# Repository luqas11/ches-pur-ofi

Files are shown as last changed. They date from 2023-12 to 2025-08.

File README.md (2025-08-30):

# ches-pur-ofi

### What is this
This project is the **firmware** and **PCB design** for the hardware interface between the [Sega Model 2](https://emulation.gametechwiki.com/index.php/Sega_Model_2) emulator and **a custom homemade cockpit** which has two **pedals**, a **steering wheel**, an **H shifter** and an **analog speedometer**. The idea is to play [Daytona USA](https://en.wikipedia.org/wiki/Daytona_USA) on the emulator while using the cockpit controls and to keep the speedometer pointer in sync with the game car speed. An [Arduino Leonardo](https://docs.arduino.cc/hardware/leonardo) board makes this interface possible, reading the input values and sending them to the PC as PC Joysick buttons and axes. Also, the board controls the servo that drives the speedometer pointer and processes the car speed value given by the emulator. A custom PCB design simplifies the setup process, allowing the user to just plug the *Leonardo* into the PCB and play, without additional wiring.  

The repo has the following project components:
- A **LUA script** that runs in the emulator and broadcasts the car speed value to the *Leonardo*
- A **C++ sketch** that is the firmware running inside the *Leonardo*, which processes the controls inputs and the speedometer motor output
- A **custom PCB** that has some pins to simplify the electrical connections between the *Leonardo* and the cockpit potentiometers and buttons

### How to use it
While in the cockpit, plug the *Leonardo* to the board and the USB to the PC. Run the emulator from the `Daytona USA.bat` script, and specify the *Leonardo* COM port number when asked to. After that, the game shuld start with all the controls operational. Axes calibration process is explained in the `firmware` readme file, and is usually needed after a hardware change (i.e. after replacing potentiometers). In the top left corner an informative text shows the port connection status, and it's behavior is also explained in the `firmware` readme.

### Some screenshots
#### Gameplay with a successful connection to the *Leonardo* (notice the top-left corner text displaying the COM port name in green):
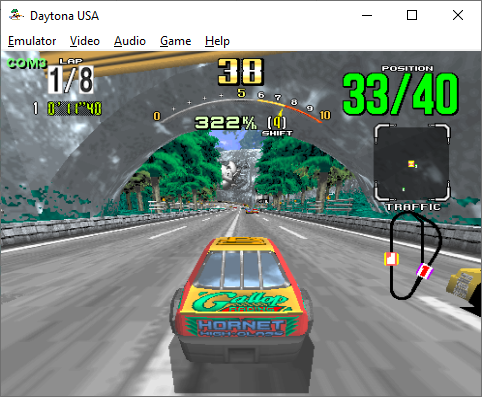
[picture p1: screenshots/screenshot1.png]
Gameplay with successful connection
  

#### Gameplay with the connection to the *Leonardo* lost (notice the top-left corner text displaying the COM port name in red):
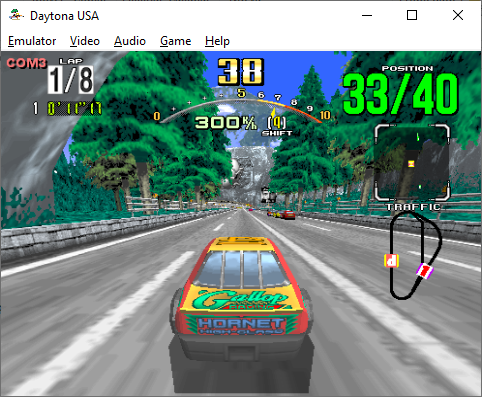
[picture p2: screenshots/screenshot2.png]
Gameplay with lost connection
  

#### PCB layout:
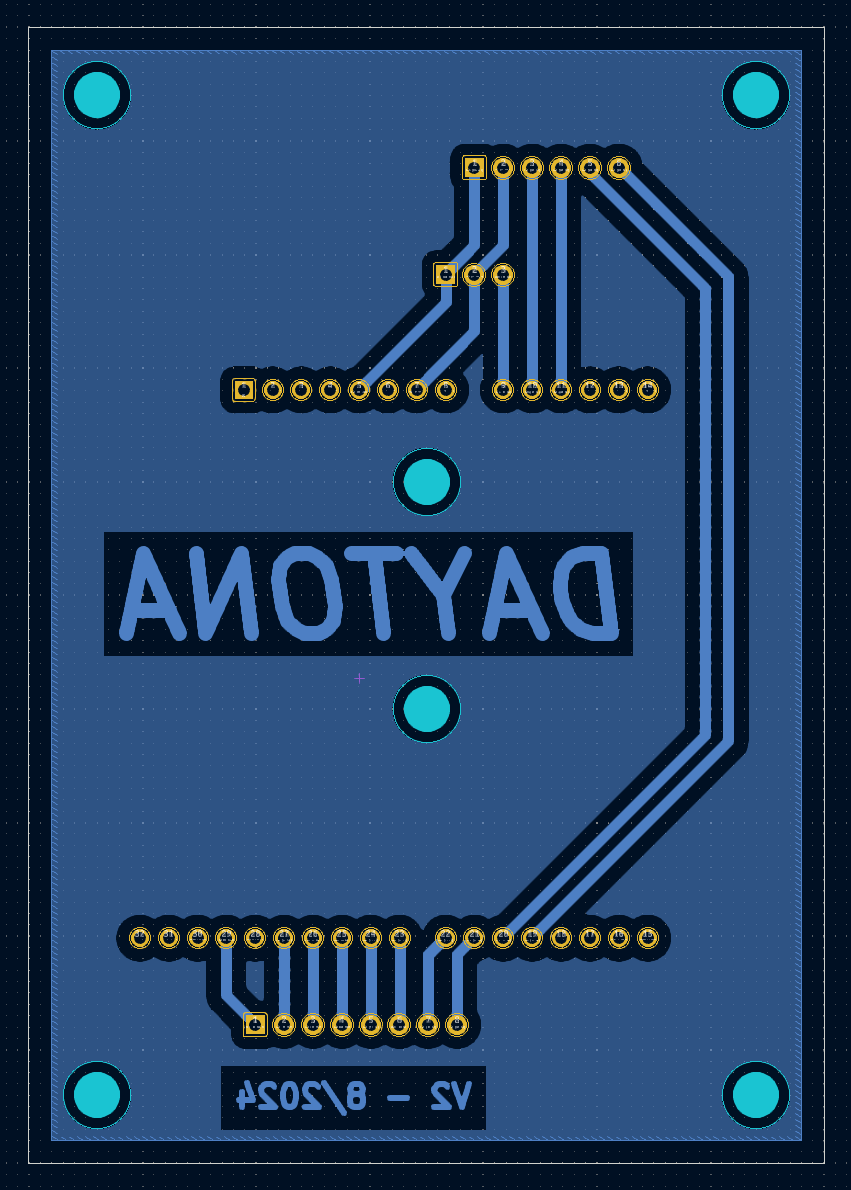
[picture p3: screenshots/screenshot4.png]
  

#### PCB 3D model:
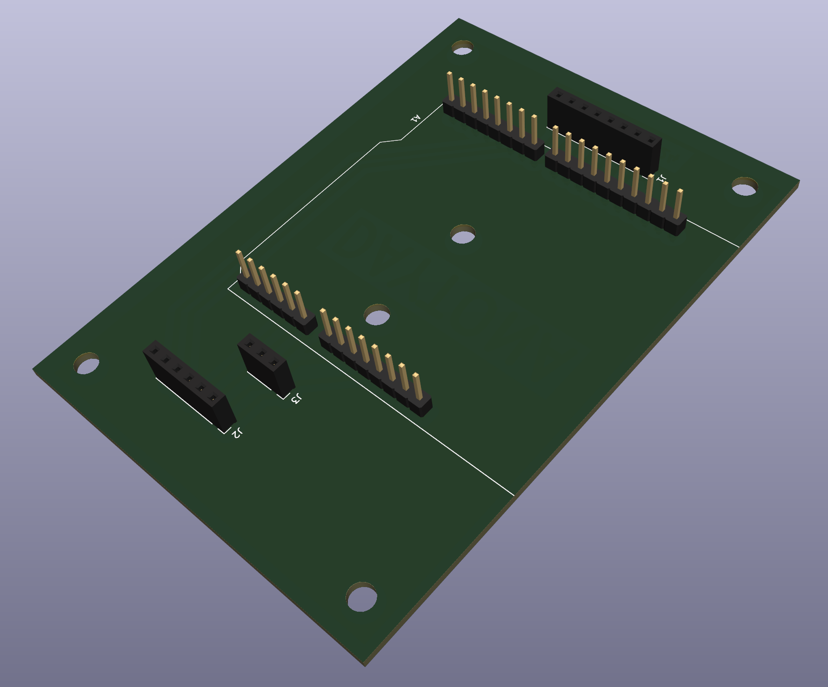
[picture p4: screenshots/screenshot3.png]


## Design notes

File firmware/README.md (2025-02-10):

# Firmware

### How this works
This firmware handles up to 8 buttons, 3 axes, and a servo motor. In the emulator, the buttons are mapped to the car shifts and the coin input, the axes are mapped to the steering, brake and accelerator, and the servo moves the physical speedometer pointer. The [Arduino Joystick Library](https://github.com/MHeironimus/ArduinoJoystickLibrary) makes this possible by configuring the *Leonardo* to appear as a PC Joystick to the PC, and giving an API that allows the Joystick buttons and axes to be pressed and moved from the board.  

### How to debug analog inputs
By setting the `DEBUG_MODE` constant to `true`, the firmware stops using the `Joystick` object and starts sending the analog inputs raw values to the serial monitor. It's useful to calibrate or debug analog inputs that are not working as expected, or to recalibrate an input after a potentiometer replacement.

### How to calibrate analog inputs
The analog inputs are constrained to the effective range of the raw values of the physical potentiometers, and mapped to a range between `0` and `1023`. Neither the wheel nor the pedals make perfect use of the whole potentiometer rotation range, so the constraining and the mapping are always necessary to normalize the raw values.  

For the pedals, the effective range must be specified in the firmware to make it work properly. For example:
```
// A brake pedal works between the raw values of 730 and 960.
// The firmware constrains it to a smaller range to add a tolerance margin, for example between 750 and 940.
// After that, it maps that range to a 0-1023 range to make the Joystick library perform a full range axis movement.
int brake = analogRead(A2);
brake = constrain(brake, 750, 940);
brake = map(brake, 750, 940, 0, 1023);
```  
Similarily, the steering wheel raw reading is not acceptable for the axis emulation. Assuming that the wheel uses the whole potentiometer range, the only relevant value for calibration is the centering. The center is sometimes mechanically deviated, so by specifying the center raw value the firmware calculates the widest range it can work, centering and mapping it. For example:
```
// A steering wheel is centered at the 525 raw value.
// The firmware calculates the closest border to the center, and takes that distance as the maximum available range for both directions (this makes the final range centered).
// After that, it constrains and maps the reading range to the new calculated range.
int steering = analogRead(A0);
int center = 525;
int range = min(1023 - center, center);
steering = constrain(steering, center - range, center + range);
steering = map(steering, center - range, center + range, 0, 1023);
```

### How to calibrate the speedometer
For the speedometer, since the rotation range of the servo is 180°, the received speed value must be mapped to a value between 180 and 0. The physical assembly of the speedometer could left the zero rotation point slightly displaced from the zero mark in the graphic scale, so an offset must be considered to correct it. At the maximum rotation point, the pointer will be at an arbitrary speed value, and that will be the maximum speed value to be used in the speed range mapping. For example:
```
// When the servo is set to zero rotation, the pointer is displaced by 6 degrees from the zero speed mark in the scale.
// An offset of 6 degrees is added to the minimum rotation value, so it will rotate between 180 - offset and 0 (180 means minimum rotation because the servo rotation direction is the opossite of the scale increasing direction).
// With the offset applied, rotating the servo to its maximum rotation point leaves the pointer at the 334 speed mark of the scale.
// The maximum speed value for the speed mapping is set to 334, to match the 0-334 effective range of the pointer over the scale.
int offset = 6;
int maxSpeed = 334;
int angle = map(min(speed.toInt(), maxSpeed), 0, maxSpeed, 180 - offset, 0);
```

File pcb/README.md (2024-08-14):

# PCB

This is a PCB design that simplifies physical wiring between the cockpit controls and the *Leonardo*. The circuit schematic and the PCB layout are printed in the `pcb-schematic.pdf` and `pcb-layout.pdf` files respectively. The 3D support model is a printable part that allows a solid attachment of the PCB to the cockpit structure.

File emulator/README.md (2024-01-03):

# Emulator

> [!IMPORTANT]  
> Since the **SEGA Model 2 Emulator** has no license file and it's webpage is down, i can't link a reference to the original author to give credits. The README file states that the author is *ElSemi*, and it's page (currently down) is http://nebula.emulatronia.com.

### How this works
The *Model 2* emulator calls the functions defined in the `daytona.lua` script during the game execution. That allows the development of additional features integrated with the emulation state and lifecycle.  
In this case, the `daytona.lua` script reads the current car speed from the RAM address `0x00505198`, and sends it through the COM port as a string with the format `XXXa`, where *XXX* is the speed value and *a* is the line ending character. It gets the board's COM port number from a configuration file named `com_port.txt`, which has a single line string with the port name in the format `COMX`, with *X* as the port number.

### Configuration
As mentioned, the COM port number is picked from the `com_port.txt` configuration file where it is written in a specific string format. The `Daytona USA.bat` script allows the user to interactivelly generate this file if it's not present. At launch, it asks the user for the port number and generates the file with the port name string. If the file already exists, it launches the game without asking anyting.

### Port status messages
In the top left corner of the screen, a small green or red text indicates the port connection status:
- If the script can't find the configuration file, the `NULL` text is shown in **red**
- If the script finds the file but can't establish a connection, the port name is shown in **red**
- If the script finds the file and establishes a successful connection, the port name is shown in **green**
- If the script loses connection with the port at any time of the gameplay, the port name turns into **red**

Notice that the script will not retry the port connection if it's lost during the gameplay, so a emulator reset is needed for reconnection.

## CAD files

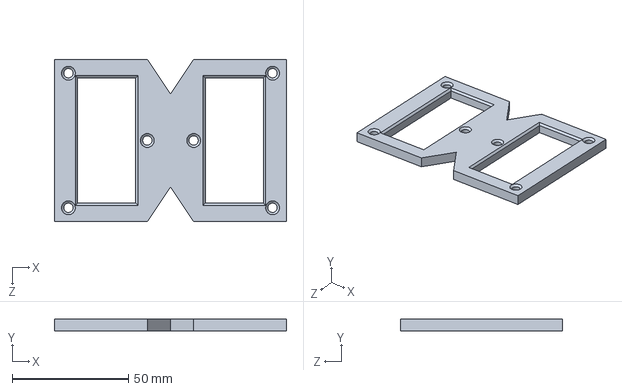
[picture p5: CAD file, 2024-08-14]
pcb/support.SLDPRT
100.0 x 5.00 x 70.0 mm

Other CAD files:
pcb/support.STL

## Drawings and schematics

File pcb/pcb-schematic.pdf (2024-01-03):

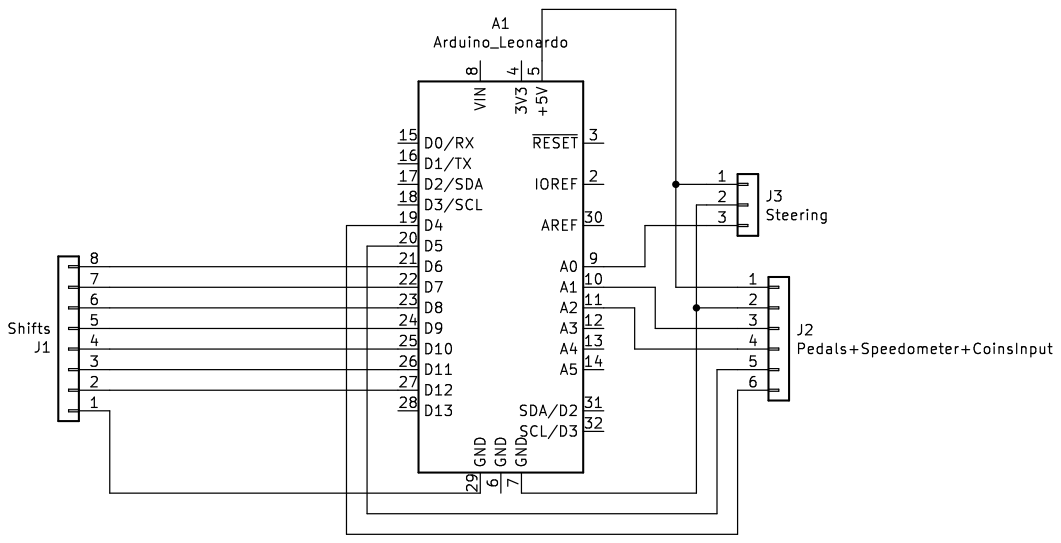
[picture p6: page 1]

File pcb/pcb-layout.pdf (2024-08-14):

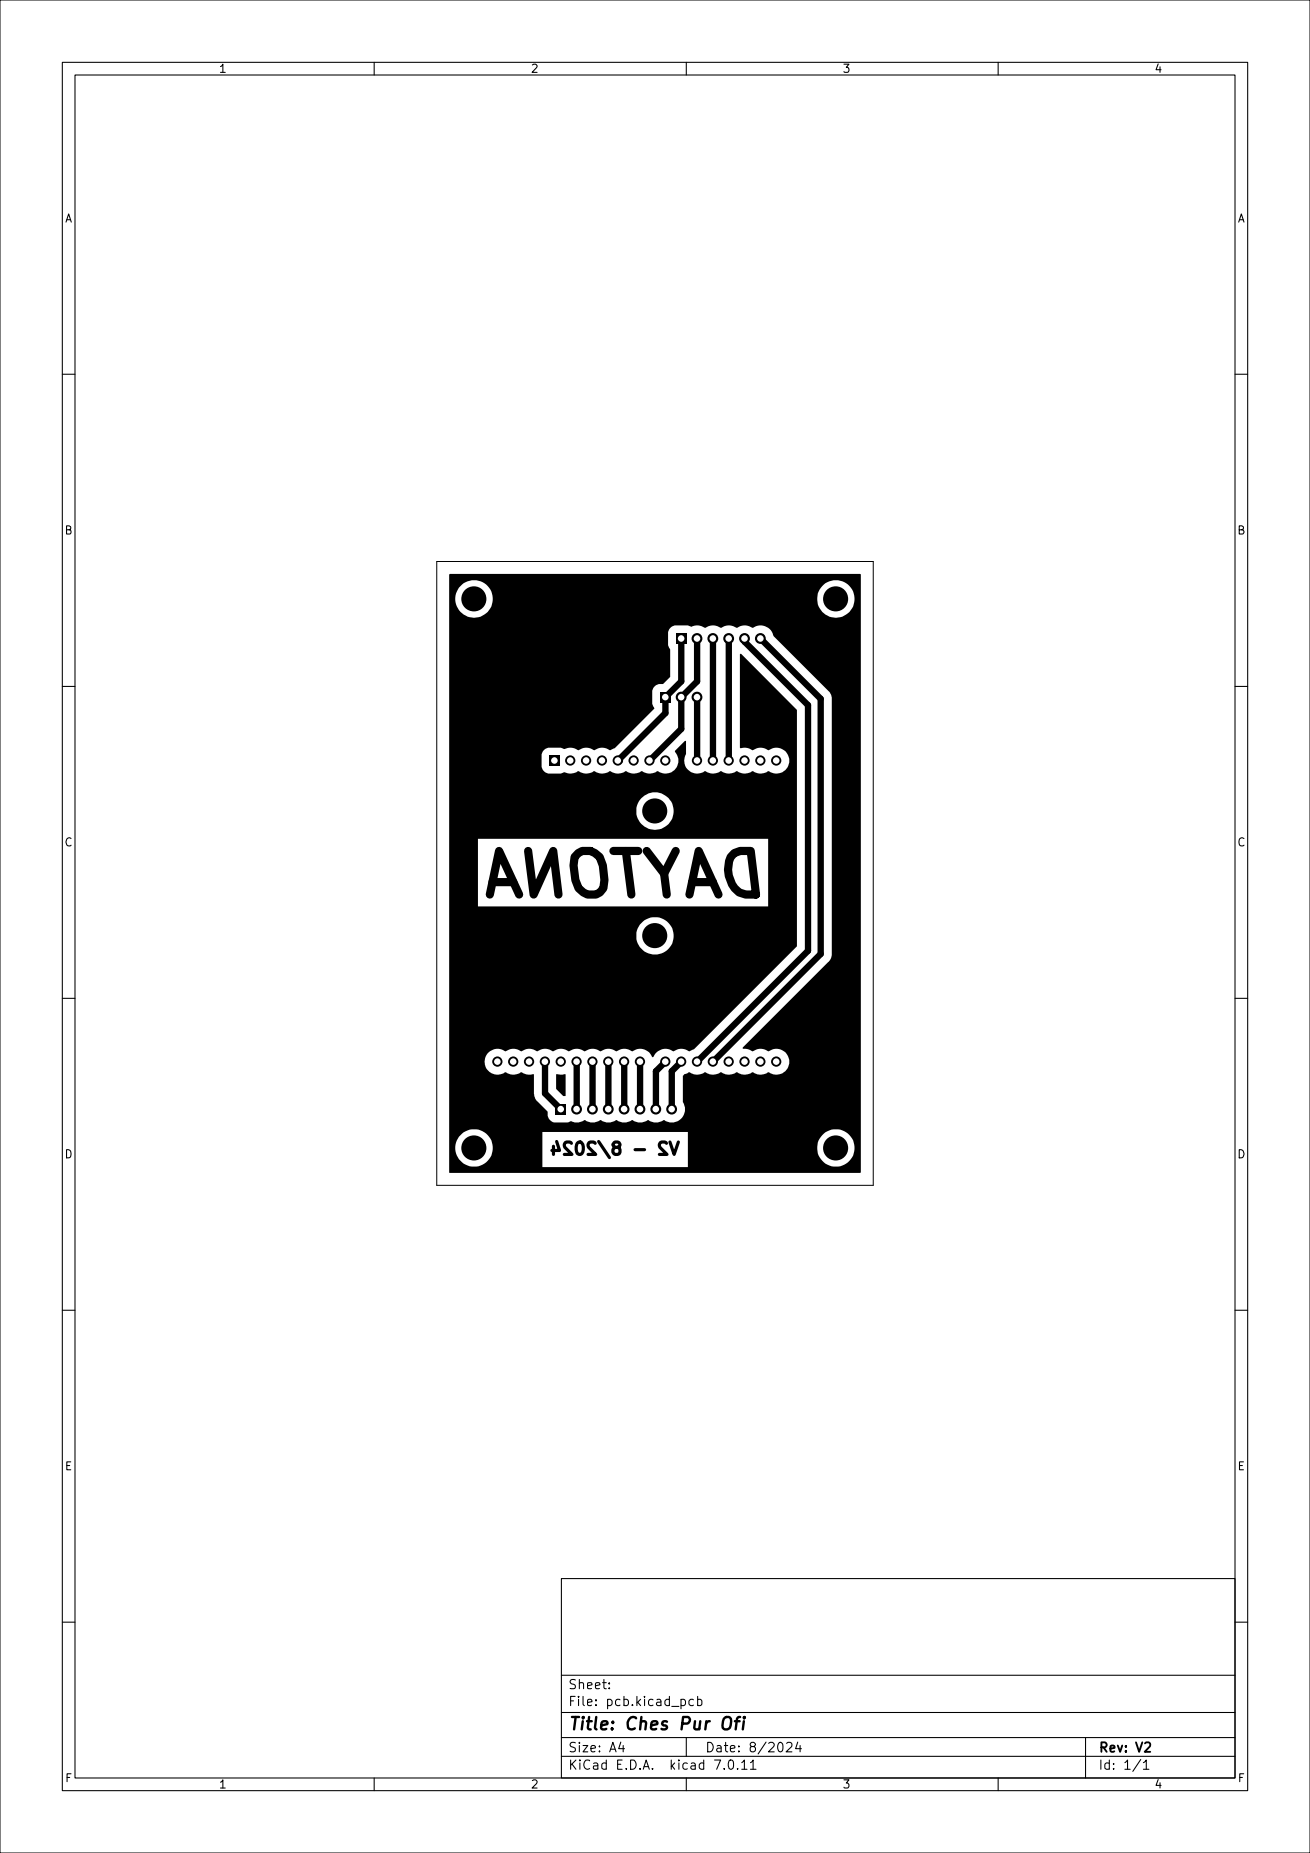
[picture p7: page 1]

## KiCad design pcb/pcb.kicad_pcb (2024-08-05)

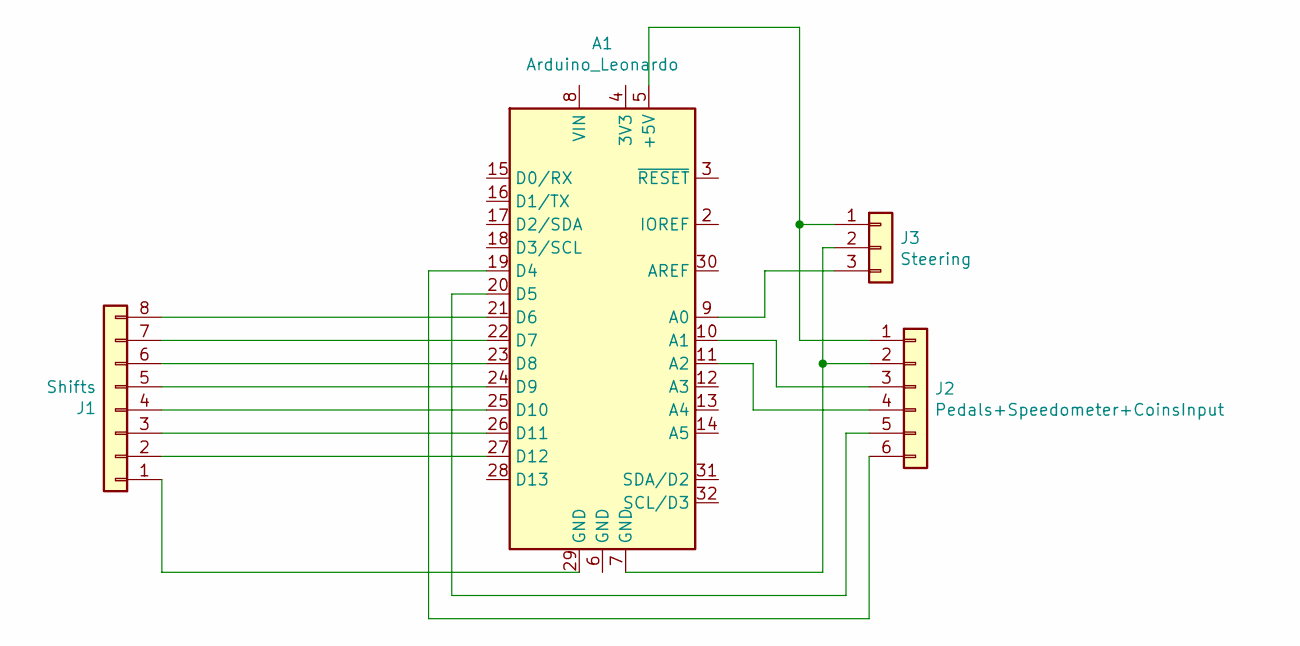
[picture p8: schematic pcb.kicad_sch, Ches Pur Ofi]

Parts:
A1: Arduino_Leonardo
J1: Shifts; PinSocket_1x08_P2.54mm_Vertical
J2: Pedals+Speedometer+CoinsInput; PinSocket_1x06_P2.54mm_Vertical
J3: Steering; PinSocket_1x03_P2.54mm_Vertical

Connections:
unnamed: A1.5 (+5V), J2.1, J3.1
unnamed: A1.9 (A0), J3.3
unnamed: A1.10 (A1), J2.3
unnamed: A1.11 (A2), J2.4
unnamed: A1.19 (D4), J2.6
unnamed: A1.20 (D5), J2.5
unnamed: A1.21 (D6), J1.8
unnamed: A1.22 (D7), J1.7
unnamed: A1.23 (D8), J1.6
unnamed: A1.24 (D9), J1.5
unnamed: A1.25 (D10), J1.4
unnamed: A1.26 (D11), J1.3
unnamed: A1.27 (D12), J1.2
unnamed: A1.29 (GND), J1.1
unnamed: A1.7 (GND), J2.2, J3.2

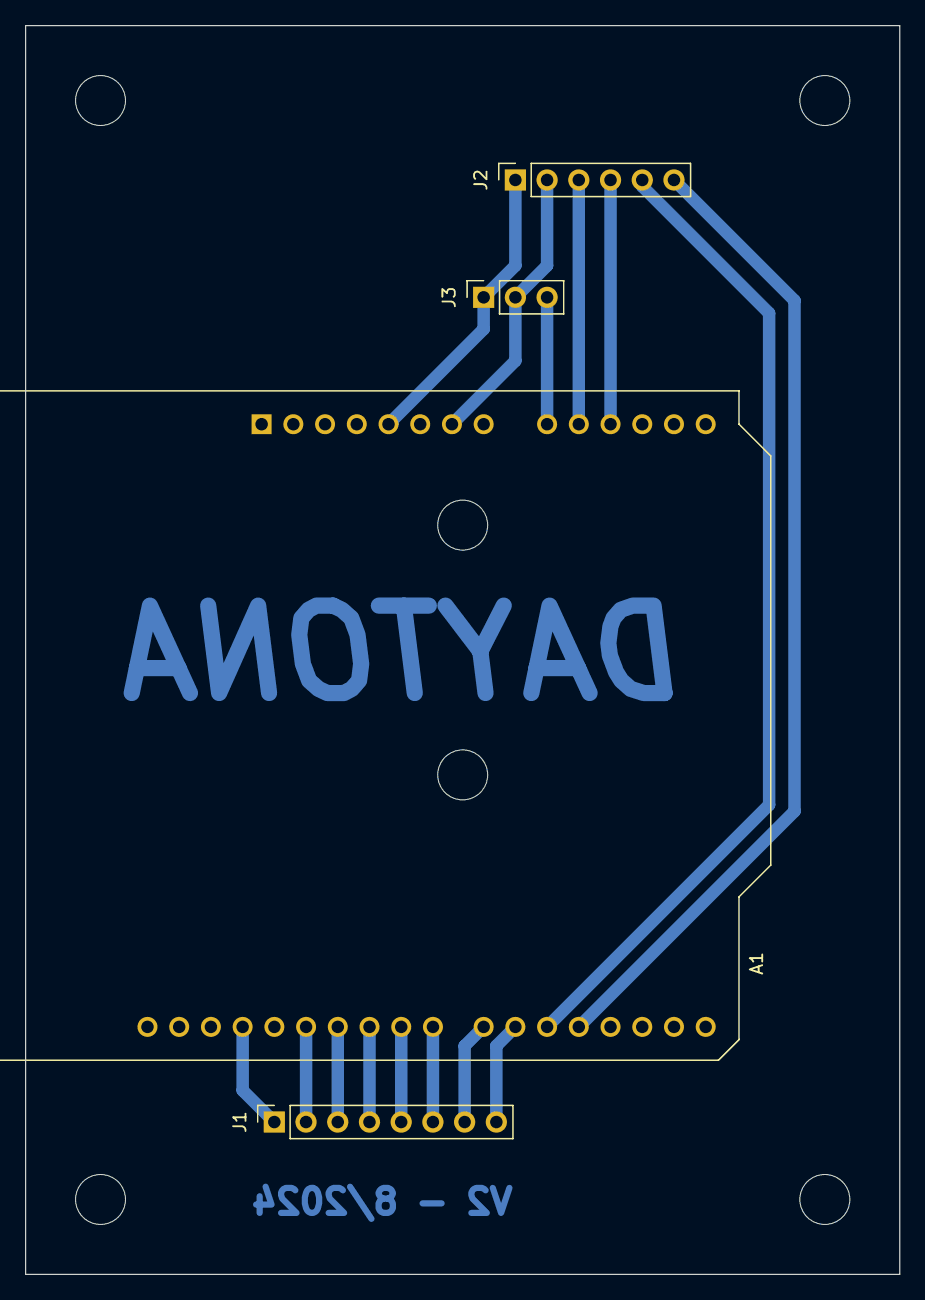
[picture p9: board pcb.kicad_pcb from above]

Board: 2 copper layers, 70.0 x 100.0 mm, 4 parts (0 on the bottom side), 15 nets.

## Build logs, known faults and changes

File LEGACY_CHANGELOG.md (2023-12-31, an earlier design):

# Historial de versiones

## Versión 1.3.0 (11/1/2023)
*Probado en la máquina del Daytona.*

#### Software:
- Calibración de potenciómetros
- Creación de script interactivo para autogenerar el archivo `com_port.txt` e iniciar el juego

## Versión 1.2 (8/12/2021)
*Probado en la máquina del Daytona.*
#### Software:
- Reemplazo de la comunicación via script C# por comunicación serie directa para el envío de la velocidad actual
- Handleo de errores de conexión con el puerto COM
- Ajustes de código en el sketch

## Versión 1.1 (4/4/2021)
*Probado con PCB propio.*
#### Software:
- Cuatro entradas digitales nuevas, ocho en totaL
- Modificación de script LUA para comunicar el valor de la velocidad actual
- Creación de un script C# para enviar la salida del LUA a Arduino por comunicación serie
- Salida para el servo del velocímetro, basado en el valor recibido del script C#

#### Hardware:
- PCB con pines para Arduino y los conectores de E/S

## Versión 1.0 (19/4/2019)  
*Probado con protoboard.*
#### Software:
- Tres entradas analógicas para potenciómetros
- Cuatro entradas digitales para botones

#### Hardware:
- Cableado en protoboard

## Versión 0.x (N/A)  
Sin documentar.

## Pinout de Arduino:

| Pin | Salida | 
|---|---|
| GND | GND |
| 5V | 5V |
| 4 | Velocímetro |
| 5 | Monedas |
| 6 | Cambio 5 |
| 7 | Cambio 2 |
| 8 | Cambio 6 |
| 9 | Cambio 3 |
| 10 | Cambio 1 |
| 11 | Cambio 4 |
| 12 | Cambio 7 |
| A0 | Volante |
| A1 | Acelerador |
| A2 | Freno |

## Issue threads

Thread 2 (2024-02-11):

Add PCB support

luqas11, 2024-02-11:
Since connecting the Leonardo board to the PCB pins requires some force, the custom board is bending and deforming over time. A simple 3D printed support could be added between the PCB and the surface where it's screwed to better distribute that force.

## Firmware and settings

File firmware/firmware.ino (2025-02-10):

#include <Servo.h>
#include <Joystick.h>

// Joystick object
Joystick_ Joystick;
// Servo motor object
Servo myServo;
// Offset of the first connected input pin
const int PIN_OFFSET = 5;
// Number of connected pins
const int PIN_COUNT = 8;
// Pin where the servo motor is connected
const int SERVO_PIN = 4;
// If true, disables the joystick and sends the input data to the serial monitor instead
const bool DEBUG_MODE = false;

void setup() {
  // Initialize objects
  Serial.begin(9600);
  myServo.attach(SERVO_PIN);
  if (!DEBUG_MODE) {
    Joystick.begin();
  }

  // Initialize input pins
  for (int i = PIN_OFFSET; i < PIN_OFFSET + PIN_COUNT; i++) {
    pinMode(i, INPUT_PULLUP);
  }
}

void loop() {
  // Read the current car speed value from the serial port, and move the servo to that speed position
  if (Serial.available()) {
    String value = Serial.readStringUntil('a');
    setServoPosition(value);
  }

  // Read the analog inputs and map the raw values to acceptable values for the Joystick object
  int steering = analogRead(A0);
  int center = 525;
  int range = min(1023 - center, center);
  steering = constrain(steering, center - range, center + range);
  steering = map(steering, center - range, center + range, 0, 1023);

  int accelerator = analogRead(A1);
  accelerator = constrain(accelerator, 90, 180);
  accelerator = map(accelerator, 90, 180, 0, 1023);

  int brake = analogRead(A2);
  brake = constrain(brake, 760, 940);
  brake = map(brake, 760, 940, 0, 1023);

  if (DEBUG_MODE) {
    // Print the raw input values in the serial monitor
    Serial.println();
    Serial.println("Raw analog inputs values:");
    Serial.println("Steering: " + (String)(analogRead(A0)));
    Serial.println("Accelerator: " + (String)(analogRead(A1)));
    Serial.println("Brake: " + (String)(analogRead(A2)));
    delay(200);
  } else {
    // Set the mapped input values to the Joystick axes
    Joystick.setRxAxis(steering);
    Joystick.setRyAxis(accelerator);
    Joystick.setRzAxis(brake);

    // Read the digital inputs and update the state of it's corresponding joystick buttons
    for (int i = PIN_OFFSET; i < PIN_OFFSET + PIN_COUNT; i++) {
      if (digitalRead(i) == LOW) {
        Joystick.pressButton(i);
      } else {
        Joystick.releaseButton(i);
      }
    }
  }
}

// Sets the servo position for a given car speed value
void setServoPosition(String speed) {
  int offset = 6;
  int maxSpeed = 334;
  int angle = map(min(speed.toInt(), maxSpeed), 0, maxSpeed, 180 - offset, 0);
  
  myServo.write(angle);
}

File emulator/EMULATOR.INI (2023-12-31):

;Configuration file for the SEGA Model 2 emulator
;All text to the right of ; is ignored (use as comments)


;Add your rom directories here (max 10)
;ROMS subdirectory in the same folder than the exe is always scanned when searching for roms
;(remove the ; form Dir1)
[RomDirs]
Dir1=C:\Program Files\Sega Model 2\Roms


[Renderer]
SoftwareVertexProcessing=0	

Wireframe=0			;Disables polygon filling (for debug purposes, don't change)
FakeGouraud=0			;Tries to guess Per-vertex colour (gouraud) from the Model2 per-poly information (flat)
Bilinear=1			;Enables bilinear filtering of textures
Trilinear=0			;Enables mipmap usage and trilinear filtering (doesn't work with some games, DoA for example)
FilterTilemaps=0		;Enables bilinear filtering on tilemaps (looks good, but can cause some stretch artifacts)
ForceManaged=0			;Forces the DX driver to use Managed textures instead of Dynamic. Use it if the emulator
				;crashes after loading or doesn't show anything
ForceSync=0
FullScreenWidth=640
FullScreenHeight=480

AutoMip=0			;Enables Direct3D Automipmap generation
MeshTransparency=0		;Enabled meshed polygons for translucency. Requires PS3.0
DrawCross=1			;Show Crosshair in gun games
GammaR=1.0			;Per Component Gamma correction (1.0 = no correction). Red
GammaG=1.0			;Green
GammaB=1.0			;Blue

WideScreenWindow=0		;Set widescreen in windows mode: 0 - 4:3, 1 - 16:9, 2 - 16:10
FSAA=0				;Enable full screen antialiasing in Direct3D



;These options are configured from menus so don't touch
FullMode=0	
Sound=1
Frameskip=-1
AutoFull=1
Filter=3



[Input]
XInput=0			;Enable support for Xbox360 compatible devices
EnableFF=0			;Enable Force Feedback Effects
HoldGears=0			;Set to 1 to return to Neutral in driving games when the gear shift key is released
UseRawInput=0			;Read mouse through Rawinput, allowing 2 mice
RawDevP1=0			;Assign specific RawInput devices to players. If you have more than 2 mice
RawDevP2=1			;set which one is assigned to each player (0-based)

;FORCE EFFECTS PARAMETERS
;FE_CENTERING Effect (Spring centering effect)
FE_CENTERING_Gain=0.5		;Global gain 
FE_CENTERING_Coefficient=10000	;0-10000
FE_CENTERING_Saturation=10000	;0-10000
FE_CENTERING_Deadband=1000	;10%

;FE_CLUTCH Effect (Friction, wheel turn hardness)
FE_CLUTCH_Gain=1.0		;Global gain 
FE_CLUTCH_Coefficient=10000	;0-10000

;FE_LEFT,FE_RIGHT (Constant force in a direction)
FE_LEFT_Gain=1.0		;Global gain 
FE_LEFT_Magnitude=10000		;0-10000
FE_RIGHT_Gain=1.0		;Global gain 
FE_RIGHT_Magnitude=10000	;0-10000


;FE_UNCENTERING (Sine force, wave the wheel, rumble)
FE_UNCENTERING_Gain=1.0		;Global gain 
FE_UNCENTERING_Magnitude=10000	;0-10000
FE_UNCENTERING_Offset=-200
FE_UNCENTERING_Phase=0
FE_UNCENTERING_Period=56000

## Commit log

2023-12-31 Add first project version
    [Daytona.kicad_pcb, Daytona.sch]
2023-12-31 Fix calibration value
2023-12-31 Remove Arduino Joystick Library copy
2024-01-02 Rename and update KiCad project
    [Daytona.kicad_pcb, Daytona.sch, pcb.kicad_pcb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]
2024-01-03 Add layout and schematic prints
    [pcb.kicad_pcb, pcb.kicad_sch]
2024-01-03 Fix schematic wording
    [pcb.kicad_sch]
2024-01-03 Add PCB and gameplay screenshots
2024-02-11 Change footprints folder name
    [pcb.kicad_pcb, pcb.kicad_sch]
2024-02-11 Fix footprints folder name
2024-08-05 Add new PCB support and update PCB layout
    [pcb.kicad_pcb, support.SLDPRT, support.STL]
2024-08-05 Reduce PCB support height
    [pcb.kicad_pcb, support.SLDPRT, support.STL]
2024-08-14 Update PCB support to avoid component collision
    [support.SLDPRT, support.STL]
2024-08-14 Add new screenshots and PCB layout print
2024-12-24 Remove VSCode Arduino extension configuration files
2024-12-24 Format firware sketch with the Arduino IDE 2 auto formatter
2024-12-31 Calibrate analog input
2024-12-31 Revert "Calibrate analog input"
    This reverts commit f309faef71e151e480f45b0960043010463a14e1.
    [firmware.ino]
2025-02-10 Add servo offset to speedometer value calculation
2026-02-01 Calibrate analog input and update game records
